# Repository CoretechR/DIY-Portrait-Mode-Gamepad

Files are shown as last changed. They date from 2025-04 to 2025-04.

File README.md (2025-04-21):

# DIY Portrait-Mode Gamepad

<div align="center">
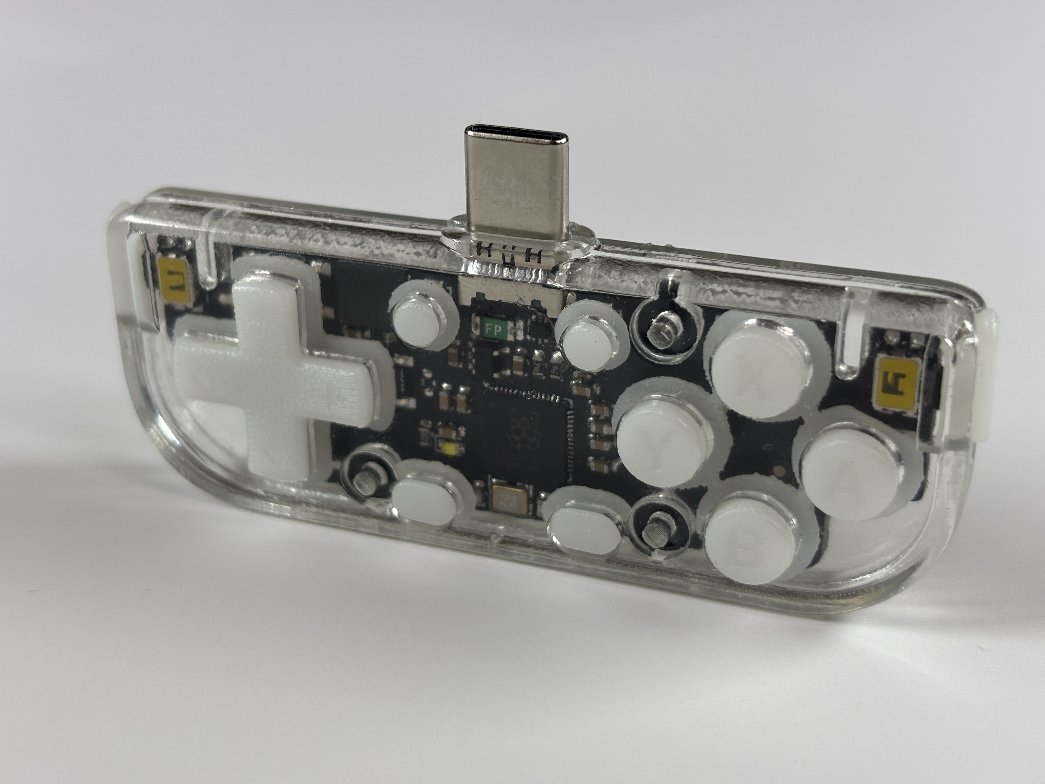
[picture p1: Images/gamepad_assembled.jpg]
  
</div>

## Overview

This RP2040-powered gamepad is designed for portrait-mode games. It plugs directly into a smartphone's USB-C port and is compatible with virtually any operating system. No Bluetooth connection or batteries are required as the gamepad communicates directly via USB and acts as a HID controller. The button layout is ideal for emulators, but the side buttons also enable landscape-mode gaming. The gamepad uses the fantasic [GP2040-CE](https://github.com/OpenStickCommunity/GP2040-CE) firmware, which also enables a local webserver Web-UI for configuration. Finally, all parts of the case and buttons are fully 3D-printable. 

<div align="center">
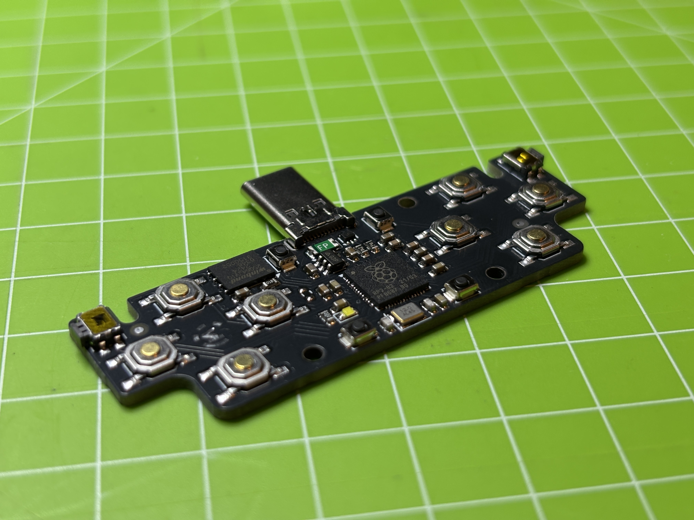
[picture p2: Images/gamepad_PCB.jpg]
  
</div>

### Features
* Small form factor
* Portrait-Mode gaming
* USB-Powered - no battery needed
* Made for the GP2040-CE firmware

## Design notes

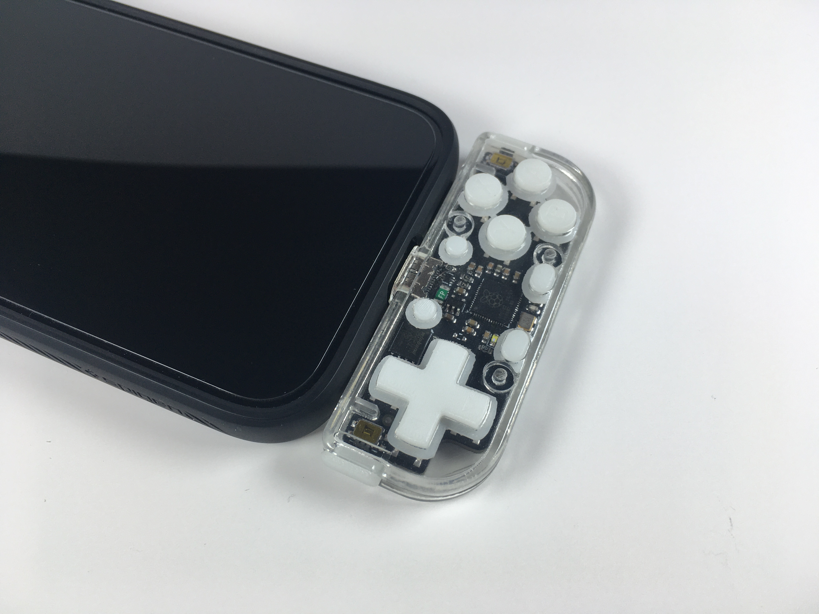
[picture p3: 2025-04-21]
Images/gamepad_plugged_in.jpg

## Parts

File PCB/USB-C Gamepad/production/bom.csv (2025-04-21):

Designator | Footprint | Quantity | Value | LCSC Part #
C1, C11, C13, C2, C3 | 0603 | 5 | 1uF | C15849
C10, C12, C14, C15, C4, C7, C8, C9 | 0603 | 8 | 100nF | C1591
C5, C6 | 0603 | 2 | 15pF | C107037
D1 | 0603 | 1 | LED | C965807
F1 | 1206 | 1 | 500mA | C220146
J1 | USB_TYPEC_PLUG_12P | 1 | USB_C_Receptacle_USB2.0 | C2879827
R2 | 0603 | 1 | 1k | C22548
R3, R4 | 0603 | 2 | 27 | C137753
R5 | 0603 | 1 | 2k2 | C114662
R7 | 0603 | 1 | 5.1k | C105580
SW1, SW2, SW3, SW4, SW6, SW7, SW8, SW9 | SW_SPST_TL3342 | 8 | SW_Push | C2762971
SW10, SW5 | Panasonic_EVQPUM_EVQPUD | 2 | SW_Push | C388642
SW11, SW12, SW13, SW14 | SW_SPST_B3U-1000P-B | 4 | SW_Push | C231329
U1 | SOT-23-5 | 1 | AP2112K-3.3 | C51118
U2 | SOT-666 | 1 | USBLC6-2P6 | C2827693
U3 | WSON-8-1EP_6x5mm_P1.27mm_EP3.4x4.3mm | 1 | W25Q64JVZPIQ | C2940197
U4 | QFN-56-1EP_7x7mm_P0.4mm_EP3.2x3.2mm | 1 | RP2040 | C2040
Y1 | Crystal_SMD_Abracon_ABM8G-4Pin_3.2x2.5mm | 1 | ABM8-272-T3 | C20625731

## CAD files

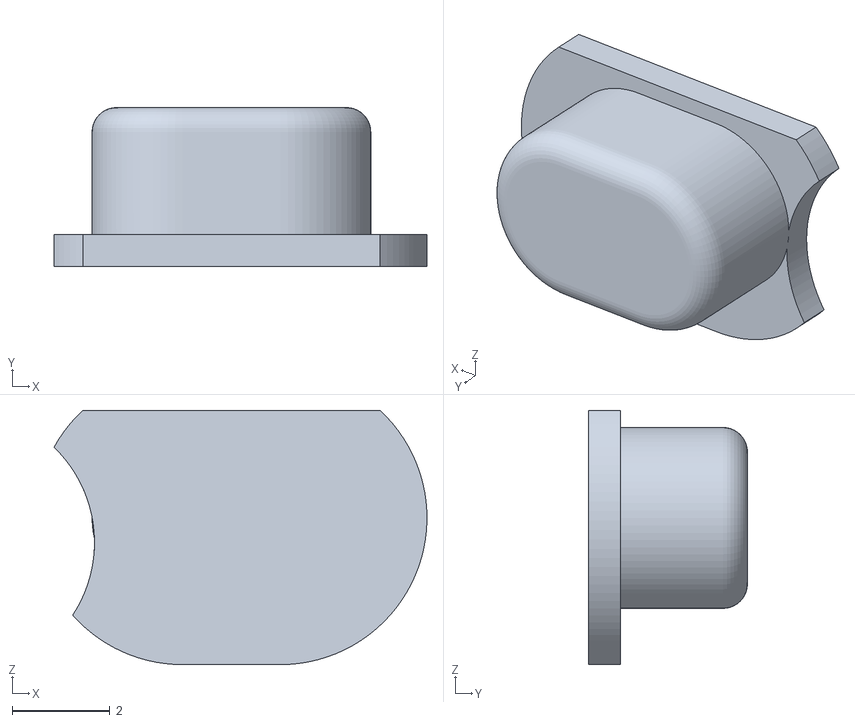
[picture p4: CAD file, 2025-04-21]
CAD/Start.stl
7.63 x 3.25 x 5.20

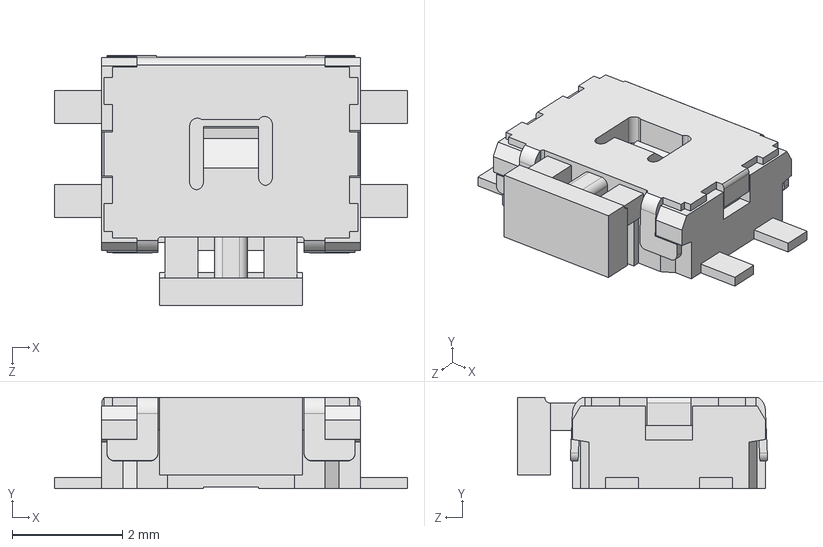
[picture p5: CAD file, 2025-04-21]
PCB/USB-C Gamepad/project_libraries/3D-models/EVQPU-JA-02K.STEP
6.40 x 1.65 x 4.54 mm

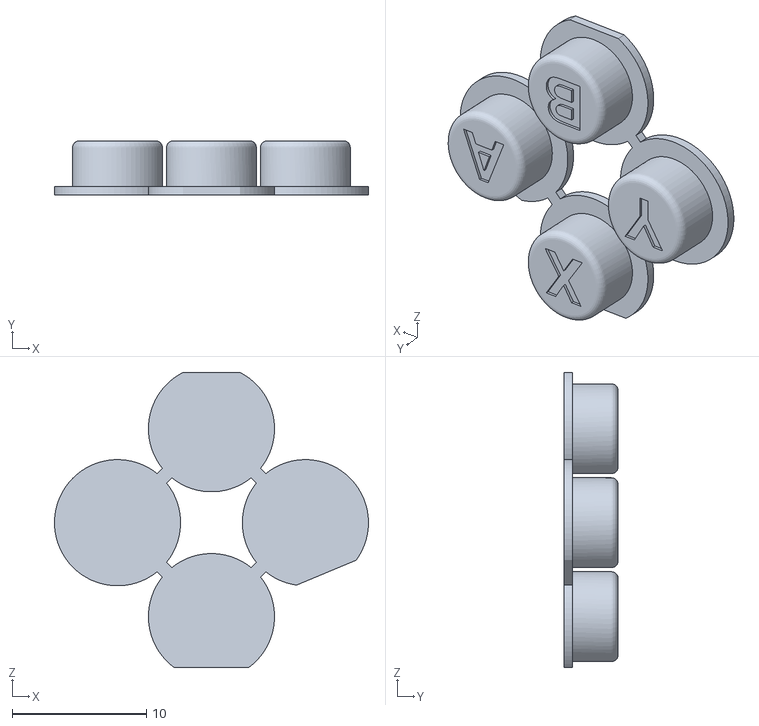
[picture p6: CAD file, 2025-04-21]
CAD/ABXY.stl
23.4 x 4.05 x 22.0

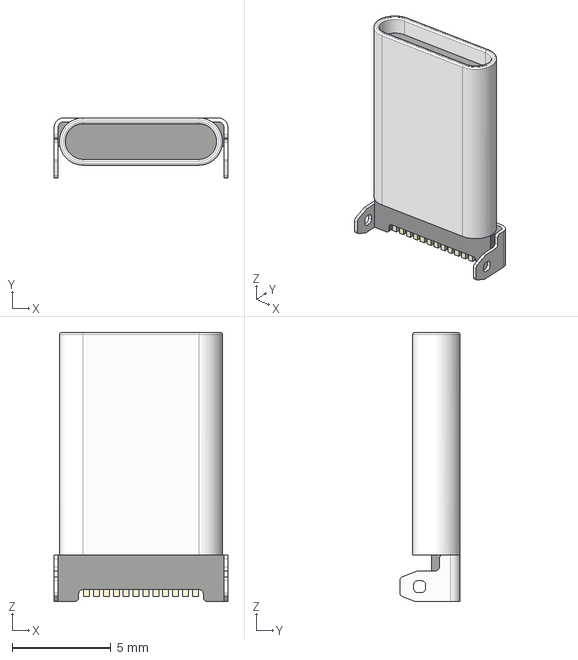
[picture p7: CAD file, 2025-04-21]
PCB/USB-C Gamepad/project_libraries/3D-models/XKB Connection U261-121N-4BS2S v1.step
8.80 x 3.05 x 13.6 mm

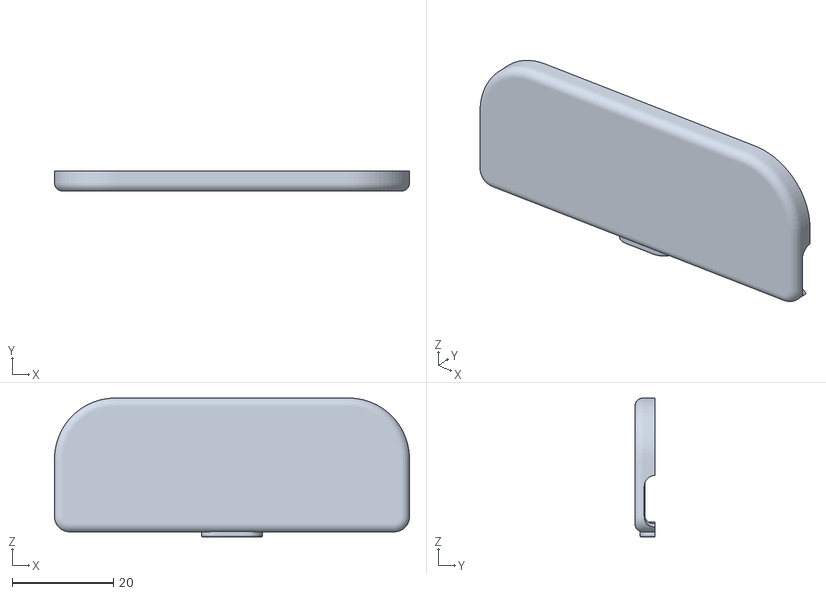
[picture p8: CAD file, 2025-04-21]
CAD/Bottom Shell.stl
70.0 x 4.00 x 27.4

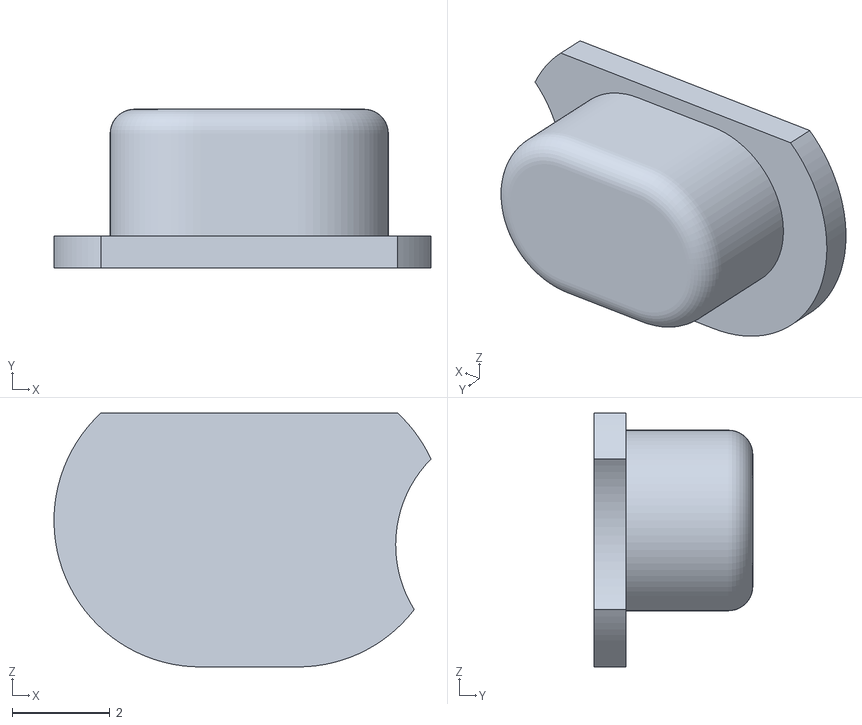
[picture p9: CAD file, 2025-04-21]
CAD/Select.stl
7.72 x 3.25 x 5.20

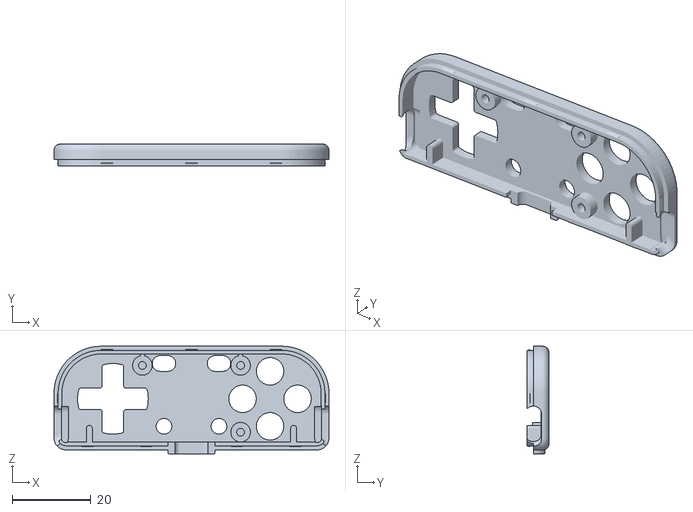
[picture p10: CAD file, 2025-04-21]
CAD/Top Shell.stl
70.0 x 5.60 x 27.4

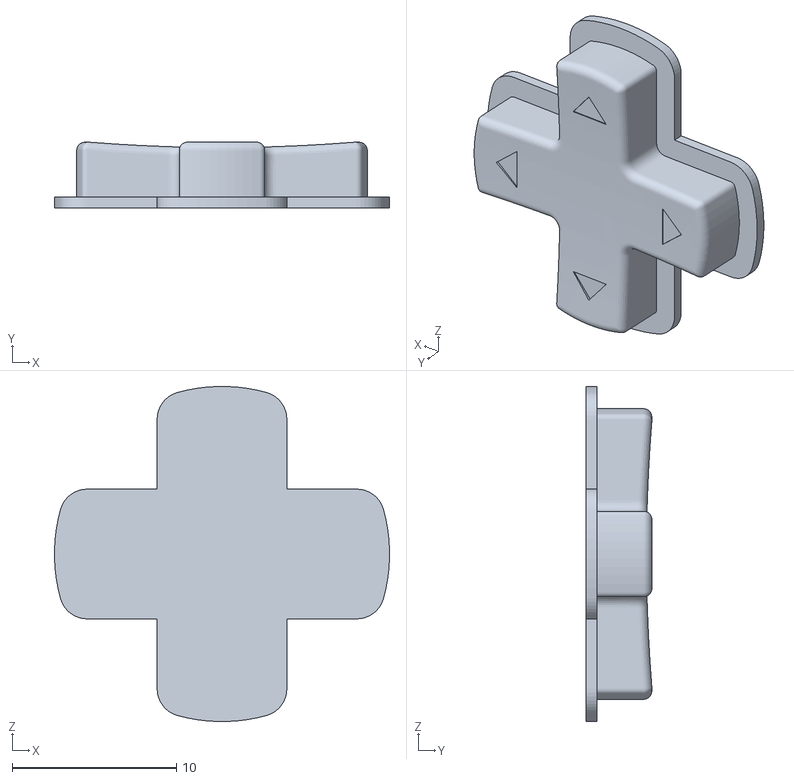
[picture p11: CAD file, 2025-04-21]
CAD/DPAD.stl
20.4 x 4.00 x 20.4

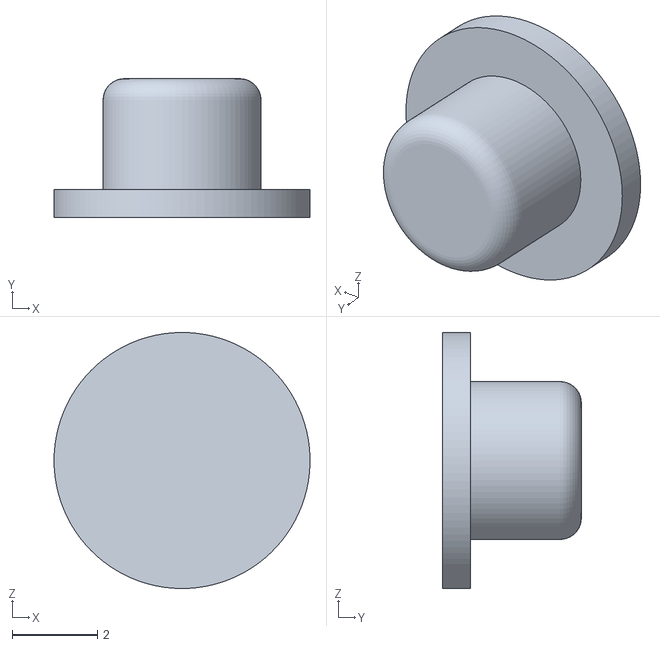
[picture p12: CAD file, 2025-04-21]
CAD/A1.stl
6.00 x 3.25 x 6.00

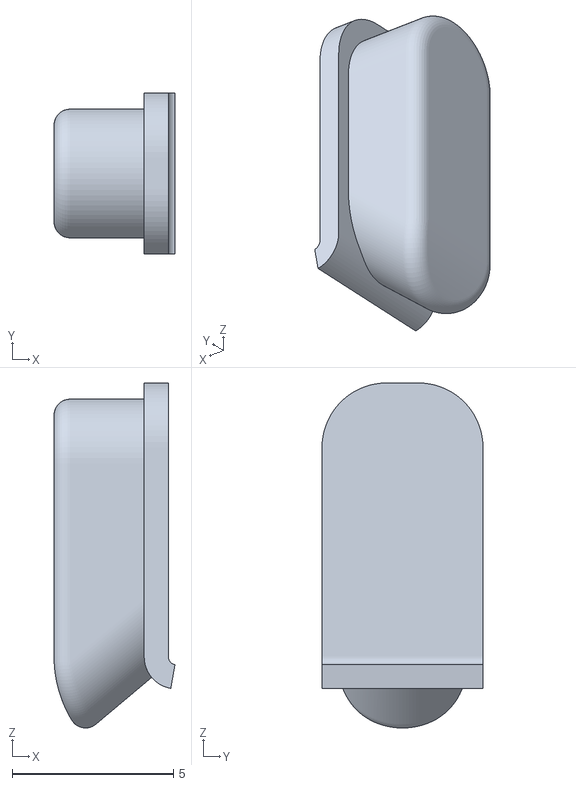
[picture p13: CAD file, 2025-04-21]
CAD/L1.stl
3.76 x 5.00 x 10.7

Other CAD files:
CAD/R1.stl
CAD/A2.stl

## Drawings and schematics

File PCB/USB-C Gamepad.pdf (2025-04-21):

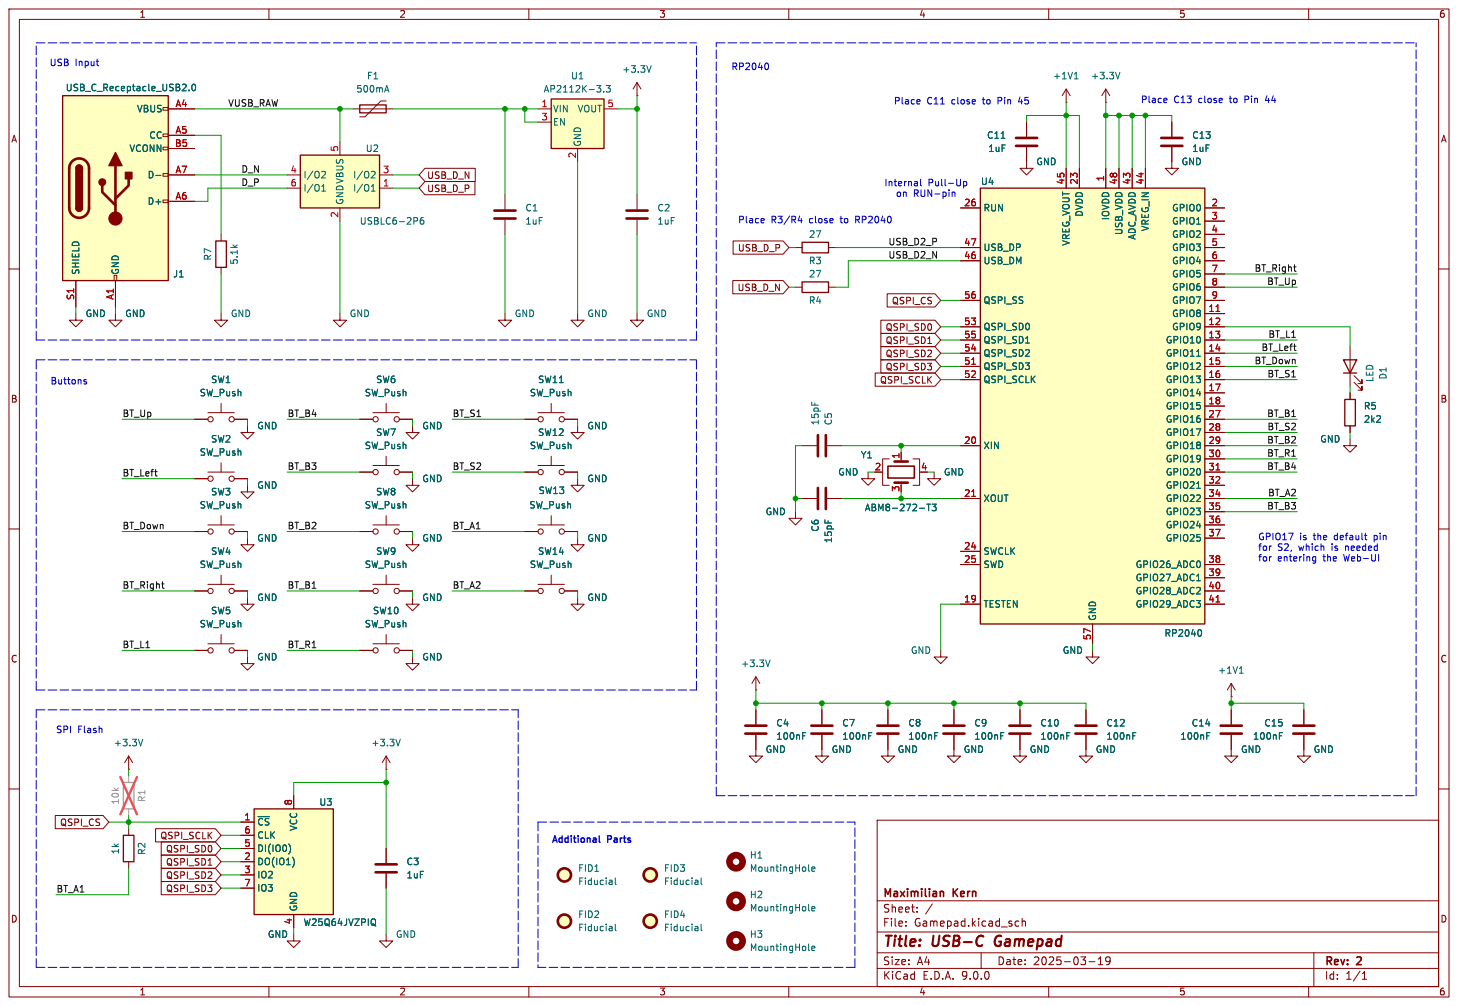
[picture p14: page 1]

for S2, which is needed

4 U3 W25Q64JVZPIQ 1kR2 +3.3V H2 MountingHole H1 MountingHole H3 MountingHole FID2 Fiducial FID1 Fiducial FID3 Fiducial FID4 Fiducial

~{CS} 1 CLK 6 DI(IO0) 5 DO(IO1) 2

Id: 1/1 Title: USB-C Gamepad

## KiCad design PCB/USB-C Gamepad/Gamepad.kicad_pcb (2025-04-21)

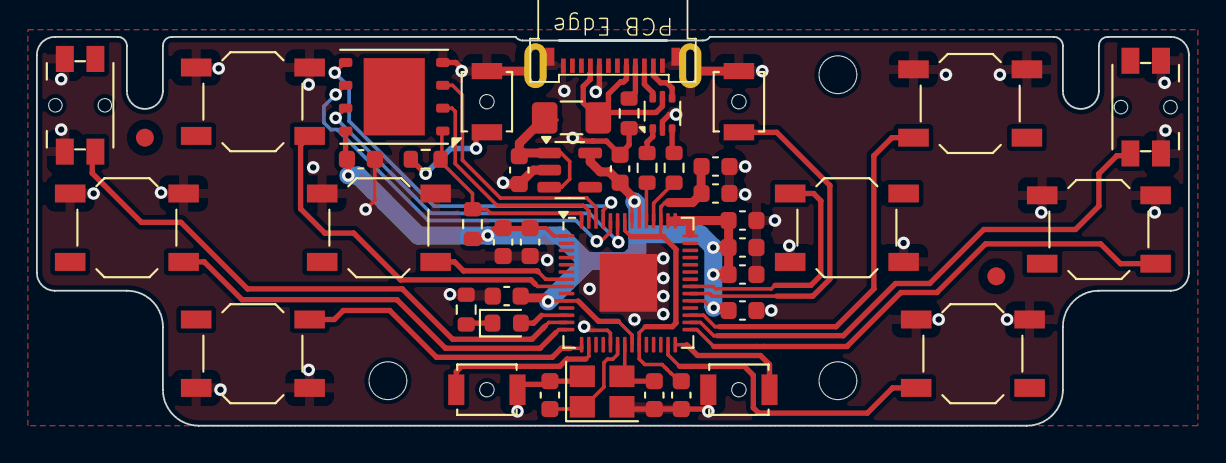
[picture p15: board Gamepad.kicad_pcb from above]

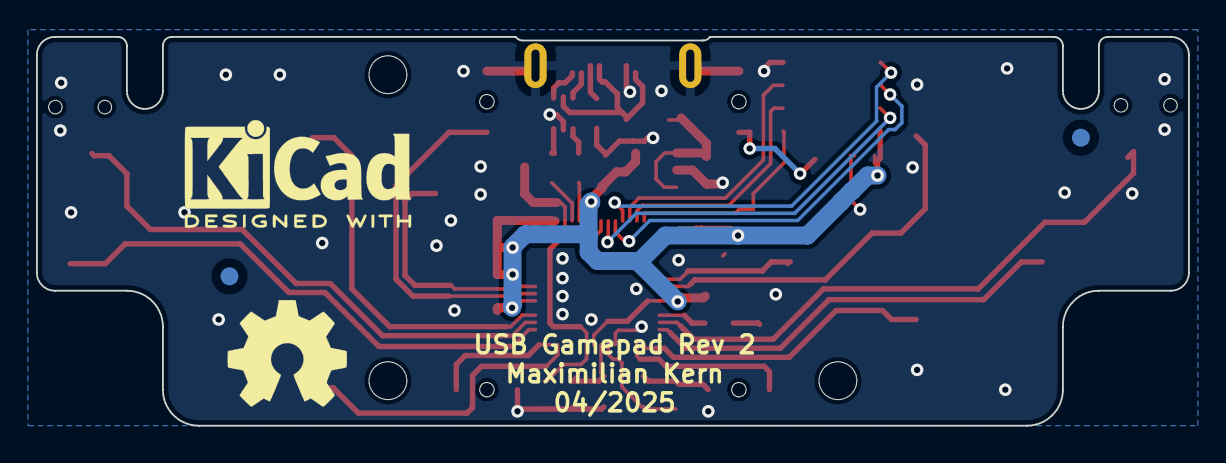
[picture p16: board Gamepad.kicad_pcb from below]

Board: 2 copper layers, 64.0 x 21.6 mm, 50 parts (2 on the bottom side), 36 nets.

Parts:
C1, C2, C3, C11, C13: 1uF; C_0603_1608Metric
C4, C7, C8, C9, C10, C12, C14, C15: 100nF; C_0603_1608Metric
C5, C6: 15pF; C_0603_1608Metric
D1: LED; LED_0603_1608Metric
F1: 500mA; Fuse_1206_3216Metric_Pad1.42x1.75mm_HandSolder
FID1, FID2, FID3, FID4: Fiducial; Fiducial_1mm_Mask2mm
H1, H2, H3: MountingHole; MountingHole_2.1mm
J1: USB_C_Receptacle_USB2.0; USB_TYPEC_PLUG_12P
R1: 10k; R_0603_1608Metric
R2: 1k; R_0603_1608Metric
R3, R4: 27; R_0603_1608Metric
R5: 2k2; R_0603_1608Metric
R7: 5.1k; R_0603_1608Metric
SW1, SW2, SW3, SW4, SW6, SW7, SW8, SW9: SW_Push; SW_SPST_TL3342
SW5, SW10: SW_Push; Panasonic_EVQPUM_EVQPUD
SW11, SW12, SW13, SW14: SW_Push; SW_SPST_B3U-1000P-B
U1: AP2112K-3.3; SOT-23-5
U2: USBLC6-2P6; SOT-666
U3: W25Q64JVZPIQ; WSON-8-1EP_6x5mm_P1.27mm_EP3.4x4.3mm
U4: RP2040; QFN-56-1EP_7x7mm_P0.4mm_EP3.2x3.2mm
Y1: ABM8-272-T3; Crystal_SMD_Abracon_ABM8G-4Pin_3.2x2.5mm

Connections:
+1V1: C11.1, C14.1, C15.1, U4.23 (DVDD), U4.45 (VREG_VOUT), U4.50 (DVDD)
+3.3V: C2.1, C3.1, C4.1, C7.1, C8.1, C9.1, C10.1, C12.1, C13.1, R1.1, U1.5 (VOUT), U3.8 (VCC), U4.1 (IOVDD), U4.10 (IOVDD), U4.22 (IOVDD), U4.33 (IOVDD), U4.42 (IOVDD), U4.43 (ADC_AVDD), U4.44 (VREG_IN), U4.48 (USB_VDD), U4.49 (IOVDD)
/BT_A1: R2.2, SW13.1
/BT_A2: SW14.1, U4.34 (GPIO22)
/BT_B1: SW9.1, U4.27 (GPIO16)
/BT_B2: SW8.1, U4.29 (GPIO18)
/BT_B3: SW7.1, U4.35 (GPIO23)
/BT_B4: SW6.1, U4.31 (GPIO20)
/BT_Down: SW3.1, U4.15 (GPIO12)
/BT_L1: SW5.2, U4.13 (GPIO10)
/BT_Left: SW2.1, U4.14 (GPIO11)
/BT_R1: SW10.2, U4.30 (GPIO19)
/BT_Right: SW4.1, U4.7 (GPIO5)
/BT_S1: SW11.1, U4.16 (GPIO13)
/BT_S2: SW12.1, U4.28 (GPIO17)
/BT_Up: SW1.1, U4.8 (GPIO6)
/D_N: J1.A7 (D-), U2.4 (I/O2)
/D_P: J1.A6 (D+), U2.6 (I/O1)
/USB_D2_N: R4.1, U4.46 (USB_DM)
/USB_D2_P: R3.1, U4.47 (USB_DP)
/VUSB_RAW: F1.1, J1.A4 (VBUS), J1.B9 (VBUS), U2.5 (VBUS)
GND: C1.2, C2.2, C3.2, C4.2, C5.2, C6.1, C7.2, C8.2, C9.2, C10.2, C11.2, C12.2, C13.2, C14.2, C15.2, J1.A1 (GND), J1.A12 (GND), J1.B12 (GND), J1.S1 (SHIELD), R5.1, R7.1, SW1.2, SW2.2, SW3.2, SW4.2, SW5.1, SW6.2, SW7.2, SW8.2, SW9.2, SW10.1, SW11.2, SW12.2, SW13.2, SW14.2, U1.2 (GND), U2.2 (GND), U3.4 (GND), U4.19 (TESTEN), U4.57 (GND), Y1.2, Y1.4
unnamed: D1.2 (A), U4.12 (GPIO9)
unnamed: D1.1 (K), R5.2
unnamed: J1.A5 (CC), R7.2
unnamed: C1.1, F1.2, U1.1 (VIN), U1.3 (EN)
unnamed: C5.1, U4.20 (XIN), Y1.1
unnamed: C6.2, U4.21 (XOUT), Y1.3
QSPI_CS: R1.2, R2.1, U3.1 (~CS), U4.56 (QSPI_SS)
QSPI_SCLK: U3.6 (CLK), U4.52 (QSPI_SCLK)
QSPI_SD0: U3.5 (DI(IO0)), U4.53 (QSPI_SD0)
QSPI_SD1: U3.2 (DO(IO1)), U4.55 (QSPI_SD1)
QSPI_SD2: U3.3 (IO2), U4.54 (QSPI_SD2)
QSPI_SD3: U3.7 (IO3), U4.51 (QSPI_SD3)
USB_D_N: R4.2, U2.3 (I/O2)
USB_D_P: R3.2, U2.1 (I/O1)
